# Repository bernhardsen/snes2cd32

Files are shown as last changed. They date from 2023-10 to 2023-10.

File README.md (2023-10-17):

# SNES2CD32 Adapter
This is a hobby project of mine that was never 100% completed, but it works for the most part in its current state.
`board` director contains the eagle files to create the PCB, and schematics with parts.
There are two current "bugs" with the PCB:
- pin 11 on IC1 should be pulled high through a 10k resistor (it's currently not connected)
- The two resistors on each side of C5 should be connected to VCC instead of GND

The chip used is an atmega8, and you need to put the arduino bootloader on it before transfering the firmware.

## Usage

To use the controller normally, just plug in the controller and you’re good.

### Re-map up/down
Most Amiga games would have you press up to jump. This is awkward and weird, even more so on a joypad. To remap up to a different button do the following:
1.  Press SELECT to enter configuration mode.
2.  Press UP to specify you want to remap UP, or DOWN if you want to remap DOWN.
3.  Press the button you want to swap with (A, B, X, Y, L or R).

### Turbo fire
You can enable turbo fire on A, B, X, Y, L and/or R, by doing the following:
1.  Press SELECT to enter configuration mode.
2.  Press START to specify you want to configure turbo fire.
3.  Press and hold the buttons you want to enable turbo fire on, and while holding them, press SELECT to confirm.

### Record/Playback macro
You can record a macro and have the controller automatically replay the inputs.

To start recording press SELECT, then L to specify you want to record a macro. The macro start recording on the next button press. It records until you press SELECT again, or the memory is full. The memory can fit around 50 button presses.

To play back a macro, press SELECT then R. The controller is not usable until the macro is done. Press SELECT while the macro is running to abort.

Timing is not 100% consistant in the current firmware.

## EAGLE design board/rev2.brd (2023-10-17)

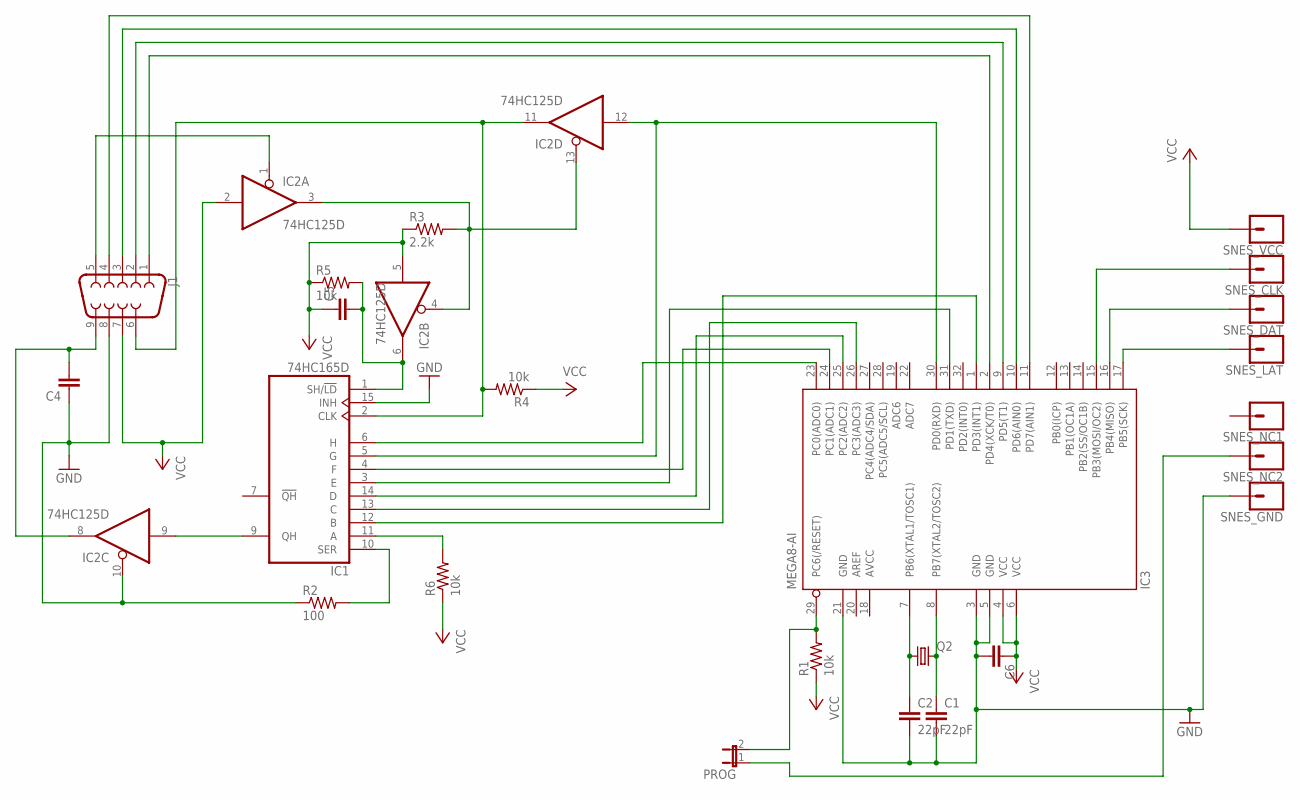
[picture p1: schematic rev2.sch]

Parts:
C1, C2: 22pF; C1206
C4, C5, C6: C-EUC1206; C1206
IC1: 74HC165D; SO16
IC2: 74HC125D; SO14
IC3: MEGA8-AI; TQFP32-08
J1: DB9FEMALE; DB9
PROG: JP1E; JP1
Q2: CRYSTALHC49S; HC49/S
R1, R4, R5, R6: 10k; R1206
R2: 100; R1206
R3: 2.2k; R1206
SNES_CLK: CONN_01PTH_2MM; 1X01_2MM
SNES_DAT: CONN_01PTH_2MM; 1X01_2MM
SNES_GND: CONN_01PTH_2MM; 1X01_2MM
SNES_LAT: CONN_01PTH_2MM; 1X01_2MM
SNES_NC1, SNES_NC2: CONN_01PTH_2MM; 1X01_2MM
SNES_VCC: CONN_01PTH_2MM; 1X01_2MM

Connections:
AVCC: IC3.18 (AVCC)
GND: C1.2, C2.2, C4.1, C6.2, IC1.8 (GND), IC1.15 (INH), IC2.7 (GND), IC2.10 (OE), IC3.3 (GND), IC3.5 (GND), IC3.21 (GND), J1.8, R2.1, SNES_GND.1
unnamed: IC3.17 (PB5(SCK)), SNES_LAT.1
unnamed: IC3.16 (PB4(MISO)), SNES_DAT.1
unnamed: IC3.15 (PB3(MOSI/OC2)), SNES_CLK.1
unnamed: C2.1, IC3.7 (PB6(XTAL1/TOSC1)), Q2.1
unnamed: C1.1, IC3.8 (PB7(XTAL2/TOSC2)), Q2.2
unnamed: IC3.29 (PC6(/RESET)), PROG.2, R1.2
unnamed: IC3.11 (PD7(AIN1)), J1.4
unnamed: IC3.10 (PD6(AIN0)), J1.3
unnamed: IC3.9 (PD5(T1)), J1.2
unnamed: IC3.2 (PD4(XCK/T0)), J1.1
unnamed: C4.2, IC2.8 (O), J1.9
unnamed: IC1.9 (QH), IC2.9 (I)
unnamed: IC2.1 (OE), J1.5
unnamed: IC1.10 (SER), R2.2
unnamed: C5.2, IC1.1 (SH/!LD), IC2.6 (O), R5.2
unnamed: IC2.3 (O), IC2.4 (OE), IC2.13 (OE), R3.2
unnamed: IC1.2 (CLK), IC2.11 (O), J1.6, R4.2
unnamed: PROG.1, SNES_NC2.1
unnamed: IC1.12 (B), IC3.1 (PD3(INT1))
unnamed: IC1.14 (D), IC3.25 (PC2(ADC2))
unnamed: IC1.13 (C), IC3.26 (PC3(ADC3))
unnamed: IC1.6 (H), IC3.23 (PC0(ADC0))
unnamed: IC1.4 (F), IC3.24 (PC1(ADC1))
unnamed: IC1.3 (E), IC3.31 (PD1(TXD))
unnamed: IC1.5 (G), IC2.12 (I), IC3.30 (PD0(RXD))
unnamed: IC1.11 (A), R6.2
VCC: C5.1, C6.1, IC1.16 (VCC), IC2.2 (I), IC2.5 (I), IC2.14 (VCC), IC3.4 (VCC), IC3.6 (VCC), J1.7, R1.1, R3.1, R4.1, R5.1, R6.1, SNES_VCC.1

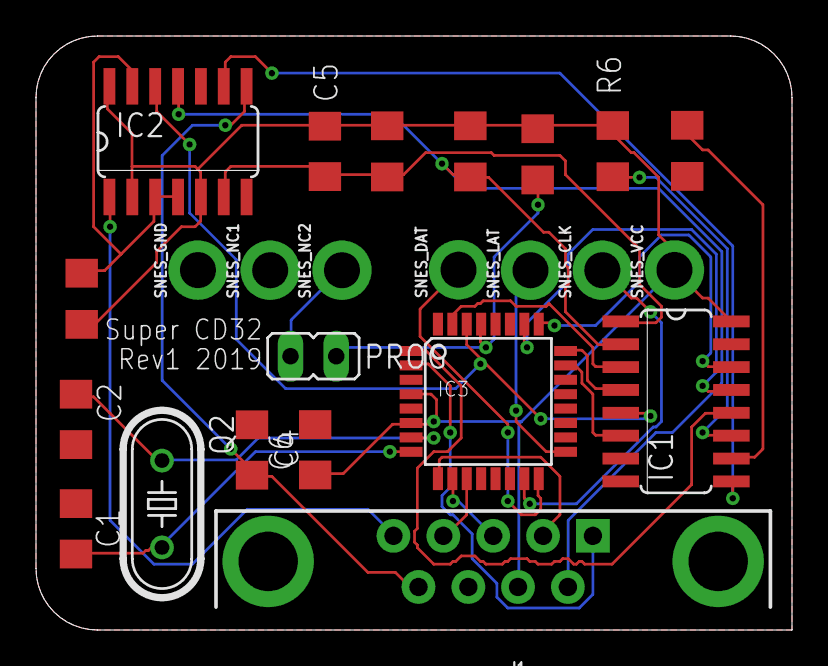
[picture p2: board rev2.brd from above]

Board: 2 copper layers, 42.0 x 33.0 mm, 24 parts (0 on the bottom side), 28 nets.

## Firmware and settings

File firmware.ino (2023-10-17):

#define CONFIG_BUTTON   B00000100
#define START_BUTTON    B00001000
#define SHOULDER_L      B00000100
#define SHOULDER_R      B00001000
#define DPAD_UP         B00010000
#define DPAD_DOWN       B00100000
#define BUTTON_B        B00000001
#define BUTTON_Y        B00000010
#define BUTTON_A        B00000001
#define BUTTON_X        B00000010

#define SWAP_ENABLED    B01000000

#define MACRO_FRAME_DELAY  19900 // old "ok" = 16200

#define TURBO_INTERVAL    4
#define PULL_DELAY        2450

#define delaySec(N)    (B11000000 | (0x1F & N))
#define delayFrm(N)    (B10000000 | (0x1F & N))

#define STATUS_LED_ON   PORTB |= B00000001
#define STATUS_LED_OFF  PORTB &= B11111110

int cState1 = 0x00;
int cState2 = 0x00;
int mState1 = 0xFF;
int mState2 = 0xFF;

byte mQx = B11001100;
byte mQy = B11001100;
byte posX = 0;
byte posY = 0;

int swapConfigUp = 0x00; // Format: RE XX XB BB - R = cState1 or cState2, BB = which bit to replace, X = Unused, E = enabled
int swapConfigDown = 0x00;

byte turboConfig = 0x00;
byte turboCount = 0;

int autoFireConfig = 0x00; // bits: ES RL AB XY
int autoFireTimer = 0x00;

byte macroMem[256];

void setup() {
  DDRB =  B00101000; // PB3 and PB5 as output, the rest as input // + PB0 (status LED)
  DDRC |= B00001111; // Set PC0 - PC3 as outputs
  DDRD |= B11111111; // Set all of PORTD to output

  PORTB |= B00001000; // Set clock high
  PORTC = B00001111;
  PORTD =  B11111111;

  macroMem[0] = 0xFF; // set 1st byte to "End macro"

  delayMicroseconds(1000); // 1ms
  readController();
  readController();
}

void loop() {
  readController();
  checkConfig();
  processButtons();
  writeOutput();
}

void readController() {
  int i;
  
  PORTB |= B00100000; // write 1 to PB5
  delayMicroseconds(12); // This delay could maybe be used to do other things, maybe do some logic and wait less
  PORTB &= B11011111; // write 0 to PB5
  delayMicroseconds(6);

  cState1 = 0x00;
  cState2 = 0x00;
  
  for(i = 0; i < 8; i++) {
    if (PINB & 0x10) {
      cState1 |= 1 << i;
    }
    PORTB &= B11110111; // write 0 to PB3
    delayMicroseconds(6);
    PORTB |= B00001000; // write 1 to PB3
    delayMicroseconds(6);
  }
  
  for(i = 0; i < 8; i++) {
    if (PINB & 0x10) {
      cState2 |= 1 << (i);
    }
    PORTB &= B11110111; // write 0 to PB3
    delayMicroseconds(6);
    PORTB |= B00001000; // write 1 to PB3
    delayMicroseconds(6);
  }
}

#define rotL(v)     ((v << 1) | (v >> 7))
#define rotR(v)     ((v >> 1) | (v << 7))

void writeOutput() {
  PORTD = cState1; // Write first 8 bits to PORTB (pin 0-7)
  PORTC = cState2 & 0x0F; // Write next 4 bits to PORTD (pin 10-13)
}

void writeBlank() {
  // No buttons pressed
  PORTD = 0xFF;
  PORTC = 0xFF;
}

int getButtonSwapConfigValue() {
  do {
    readController();
  } while (cState1 == 0xFF && cState2 == 0xFF); // Wait for a button to be pressed

  if (!(cState1 & B00010000) || !(cState1 & B00100000)) { // Up or down button
    return B00000000; // Disable button swap
  } else if (!(cState1 & B00000010)) { // Y button
    return B01000001;
  } else if (!(cState1 & B00000001)) { // B button
    return B01000000;
  } else if (!(cState2 & B00000001)) { // A button
    return B11000000;
  } else if (!(cState2 & B00000010)) { // X button
    return B11000001;
  } else if (!(cState2 & B00000100)) { // L button
    return B11000010;
  } else if (!(cState2 & B00001000)) { // R button
    return B11000011;
  }
}

void configTurbo() {
  do {
    readController();
  } while (cState1 & CONFIG_BUTTON); // Wait until select is pressed
  turboConfig = 0x00;
  
  // read what face buttons are pressed and write to turbo config
  if (!(cState1 & BUTTON_B)) {
    turboConfig |= B00000001;
  }
  if (!(cState1 & BUTTON_Y)) {
    turboConfig |= B00000010;
  }
  if (!(cState2 & BUTTON_A)) {
    turboConfig |= B00000100;
  }
  if (!(cState2 & BUTTON_X)) {
    turboConfig |= B00001000;
  }
  if (!(cState2 & SHOULDER_L)) {
    turboConfig |= B00010000;
  }
  if (!(cState2 & SHOULDER_R)) {
    turboConfig |= B00100000;
  }
}

void applyTurbo() {
  if (!turboConfig) {
    return;
  }
  turboCount++;
  if (turboCount < TURBO_INTERVAL) {
    return;
  }
  turboCount = 0;
  
  if (turboConfig & 0x80) {
    if (turboConfig & 0x01) {
      cState1 |= BUTTON_B;
    }
    if (turboConfig & 0x02) {
      cState1 |= BUTTON_Y;
    }
    if (turboConfig & 0x04) {
      cState2 |= BUTTON_A;
    }
    if (turboConfig & 0x08) {
      cState2 |= BUTTON_X;
    }
    if (turboConfig & 0x10) {
      cState2 |= SHOULDER_L;
    }
    if (turboConfig & 0x20) {
      cState2 |= SHOULDER_R;
    }
    
    turboConfig &= 0x7F;
  } else {
    turboConfig |= 0x80;
  }
}


void buttonSwap() {
  if (!(swapConfigUp & SWAP_ENABLED)) {
    return;
  }
  boolean upValue = (cState1 & B00010000) == B00010000;
  boolean swapValue = (((swapConfigUp & 0x80) ? cState2 : cState1) >> (swapConfigUp & 0x07)) & 0x01 == 0x01;
  
  if (swapValue) {
    // Set the up bit
    cState1 |= B00010000;
  } else {
    // Clear up bit
    cState1 &= B11101111;
  }
  
  if (upValue) {
    // Set bit
    if (swapConfigUp & 0x80) { // cState2
      cState2 |= 1 << (swapConfigUp & 0x07);
    } else { // cState1
      cState1 |= 1 << (swapConfigUp & 0x07);
    }
  } else {
    // Clear bit
    if (swapConfigUp & 0x80) { // cState2
      cState2 &= 0xFF ^ (1 << (swapConfigUp & 0x07));
    } else { // cState1
      cState1 &= 0xFF ^ (1 << (swapConfigUp & 0x07));
    }
  }
}

void buttonSwapDown() {
  if (!(swapConfigDown & SWAP_ENABLED)) {
    return;
  }
  boolean downValue = (cState1 & B00100000) == B00100000;
  boolean swapValue = (((swapConfigDown & 0x80) ? cState2 : cState1) >> (swapConfigDown & 0x07)) & 0x01 == 0x01;
  
  if (swapValue) {
    // Set the up bit
    cState1 |= B00100000;
  } else {
    // Clear up bit
    cState1 &= B11011111;
  }
  
  if (downValue) {
    // Set bit
    if (swapConfigUp & 0x80) { // cState2
      cState2 |= 1 << (swapConfigDown & 0x07);
    } else { // cState1
      cState1 |= 1 << (swapConfigDown & 0x07);
    }
  } else {
    // Clear bit
    if (swapConfigUp & 0x80) { // cState2
      cState2 &= 0xFF ^ (1 << (swapConfigDown & 0x07));
    } else { // cState1
      cState1 &= 0xFF ^ (1 << (swapConfigDown & 0x07));
    }
  }
}

void processButtons() {
  applyTurbo();
  buttonSwap();
  buttonSwapDown();
}

void checkConfig() {
  if (cState1 & CONFIG_BUTTON) {
    return; // Select button not pressed, so we do nothing
  }
  PORTB |= B00000010;
  debounce();
  
  writeBlank(); // Write that no buttons are pressed to output
  // wait for next button press
  while (cState1 == 0xFF && cState2 == 0xFF) {
    delayMicroseconds(MACRO_FRAME_DELAY); // wait ~16ms
    readController();
  }
  if (!(cState1 & START_BUTTON)) {
    // Start button pressed
    debounce();
    configTurbo();
  } else if (!(cState1 & DPAD_UP)) {
    // Up pressed, config Up button swap
    debounce();
    swapConfigUp = getButtonSwapConfigValue();
  } else if (!(cState1 & DPAD_DOWN)) {
    debounce();
    swapConfigDown = getButtonSwapConfigValue();
  } else if (!(cState2 & SHOULDER_L)) {
    debounce();
    recordMacro();
  } else if (!(cState2 & SHOULDER_R)) {
    // debounce(); Don't debounce here because we want the macro to start immediatly.
    playBackMacro();
  }
  debounce();
  PORTB &= B11111101;
}

// Wait for all buttons to be released
void debounce() {
  while (cState1 != 0xFF || cState2 != 0xFF) {
    delayMicroseconds(16000); // wait 16ms
    readController();
  }
}

/**

Format: CCCPPPPP


CCC
100 = wait Frame          4
110 = wait half seconds   6
000 = button down     0
001 = button up         1
111 = End macro           7

1000 = wait P = 
110p = wait seconds - (max 30 seconds)
000x = button down
001x = button up
1111 = end of routine
*/


void recordMacro() {
  byte macroPointer = 0;
  byte frameDelay = 0;
  byte secondDelay = 0;
  
  byte lastState1 = 0xFF;
  byte lastState2 = 0xFF;

  do {
    delayMicroseconds(16000);
    readController();
  } while (cState1 == 0xFF && cState2 == 0xFF);
  // wait for first button input
  
  while ((cState1 & CONFIG_BUTTON) && macroPointer < 255) {
    if (cState1 != lastState1 || cState2 != lastState2) {
      if (secondDelay > 0) {
        macroMem[macroPointer++] = delaySec(secondDelay);
        secondDelay = 0;
      }
      if (frameDelay > 0) {
        macroMem[macroPointer++] = delayFrm(frameDelay);
        frameDelay = 0;
      }
      
      // Write button change
      byte diff1 = lastState1 ^ cState1;
      byte diff2 = lastState2 ^ cState2;

      for (int i = 0; i < 8; i++) {
        if ((diff1 >> i) & 0x01) { // bit i in cState1 changed
          macroMem[macroPointer++] = (((cState1 >> i) & 0x01) << 5) + i;
        }
        if ((diff2 >> i) & 0x01) { // bit i in cState2 changed
          macroMem[macroPointer++] = (((cState2 >> i) & 0x01) << 5) + i + 8;
        }
      }
      
      lastState1 = cState1;
      lastState2 = cState2;
    }
    
    // Write the button output, so that we can see what we are recording
    processButtons();
    writeOutput();
    
    delayMicroseconds(MACRO_FRAME_DELAY); // Ajust this bad boy to make it more accurate
    frameDelay++;
    if (frameDelay == 30) {
      frameDelay = 0;
      secondDelay++;
    }
    if (secondDelay == 30) {
      macroMem[macroPointer++] = 0xDE; // Wait 30 seconds
      secondDelay = 0;
    }
    readController();
  }
  
  macroMem[macroPointer] = 0xFF; // Write end of macro command;
}

void playBackMacro() {
  byte macroPointer = 0;
  byte macroState1 = 0xFF;
  byte macroState2 = 0xFF;
  
  while (macroMem[macroPointer] != 0xFF && macroPointer < 255) {
    readController();
    if (!(cState1 & CONFIG_BUTTON)) {
      return; // Config button = cancel playback
    }
    
    boolean buttonsChanged = false;
    byte button;
  
    switch ((macroMem[macroPointer] >> 5) & 0x07) {
      case 0x04: // Wait P frames;
        for (int i = (macroMem[macroPointer] & 0x1F); i > 0; i--) {
          delayMicroseconds(MACRO_FRAME_DELAY);
        }
        break;
      case 0x06: // Wait P seconds / 2 (30 * frames)
        for (int i = (macroMem[macroPointer] & 0x1F); i > 0; i--) {
          for (int j = 0; j < 30; j++) {
            delayMicroseconds(MACRO_FRAME_DELAY);
          }
        }
        break;
      case 0x00: // Button pressed
        button = macroMem[macroPointer] & 0x1F;
        if (button < 8) {
          macroState1 &= ~(1 << button);
        } else {
          macroState2 &= ~(1 << (button - 8));
        }
        buttonsChanged = true;
        break;
      case 0x01: // Button released
        button = macroMem[macroPointer] & 0x1F;
        if (button < 8) {
          macroState1 |= 1 << button;
        } else {
          macroState2 |= 1 << (button - 8);
        }
        buttonsChanged = true;
        break;
    }
    
    if (buttonsChanged) {
      cState1 = macroState1;
      cState2 = macroState2;
      processButtons(); // We still want to apply button swap and auto-fire, since the macro is recorded before this.
      writeOutput();
    }
    
    macroPointer++;
  }
}

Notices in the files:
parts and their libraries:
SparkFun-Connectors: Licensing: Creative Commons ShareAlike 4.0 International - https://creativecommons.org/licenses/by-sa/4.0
